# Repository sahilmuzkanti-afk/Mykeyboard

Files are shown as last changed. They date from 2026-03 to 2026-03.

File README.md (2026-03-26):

This is my personal 81% mechanical keyboard 
using a Raspberry Pi Pico (RP2040) microcontroller, custom PCB, matrix wiring with diodes, USBC connectivity, and programmable firmware.

To use this , 
i will assemble all the parts and flash the included firmware onto the microcontroller. Once assembled and programmed, the keyboard functions as a fully customizable mechanical keyboard.

I built this keyboard to learn more about PCB design and hardware projects. 
It was also a fun way to create something useful for everyday typing and coding.

FREE CAD SOURCE FILE ( DUE TO 25 MB LIMIT )
https://drive.google.com/file/d/17SE7lhAPqHGHGGqQkhNdOv5Vobzph8jl/view?usp=sharing
PCB
BOTTOM
ASSEMBLY
ASSEMBLY 2nd angle
TOP
SCHEMATIC
PLATE
PCB STEP
PCB 3D VIEW
ERC ( 0 ERROR )
DRC ( 0 ERROR )



## Bill of Materials (BOM)

| Component | Quantity | Description | Price (USD) | Supplier | Link |
|---|---|---|---|---|---|
| Raspberry Pi Pico | 1 | RP2040 microcontroller board used to control the keyboard | $8.34 | Amazon | https://amzn.in/d/0fqm6Hu0 |
| Gateron KS-9 Key Switches | 81 | Mechanical keyboard switches for each key | $25.37 | Amazon | https://amzn.in/d/0cwz2P6f |
| 1N4148 Diode | 81 | Signal diode used in keyboard matrix to prevent ghosting | $2.74 | Amazon | https://amzn.in/d/0dybXXSo4 |
| M3x16mm Screws | 50 | Screws used to mount keyboard case and PCB | $2.23 | Amazon | https://amzn.in/d/06ymnZXY |
| Mechanical Keyboard Keycap Set | 81 | Keycaps used for mechanical keyboard switches | $15.69 | Amazon | https://amzn.in/d/022G7hkw |
| Cherry Clip-in Stabilizers | 1 | Stabilizer kit for large keys | $8.98 | Keebsmod | https://www.keebsmod.com/products/cherry-clip-in-stabilizers |
| Custom Keyboard PCB | 1 | Custom PCB manufactured for the keyboard | $33.85 | JLCPCB | Cart screenshot in README |
| **Total Project Cost** |  |  | **$97.20** |  |  |

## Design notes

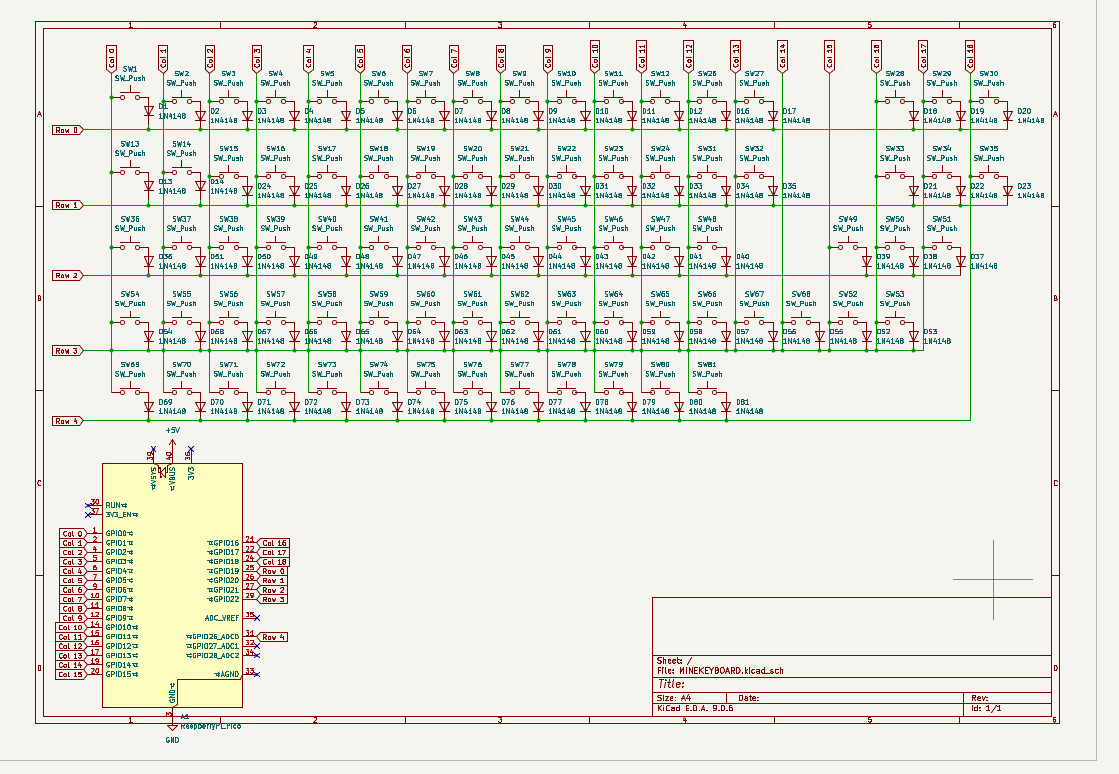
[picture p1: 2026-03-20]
IMAGES/SCHEMATIC.png

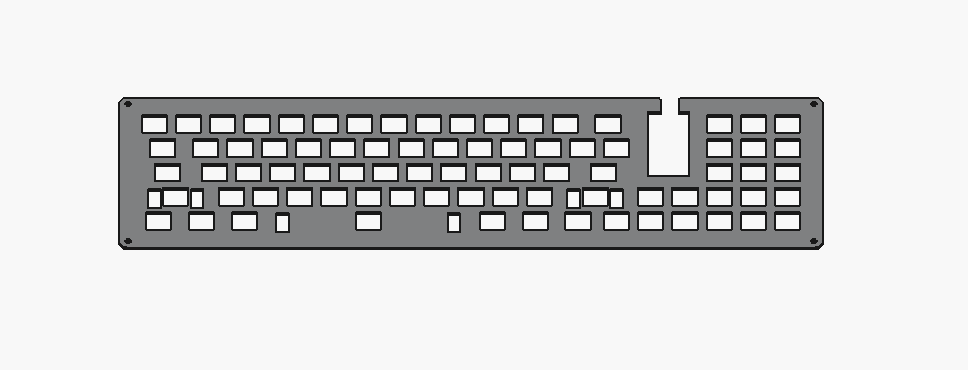
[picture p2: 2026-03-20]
IMAGES/PLATE.png

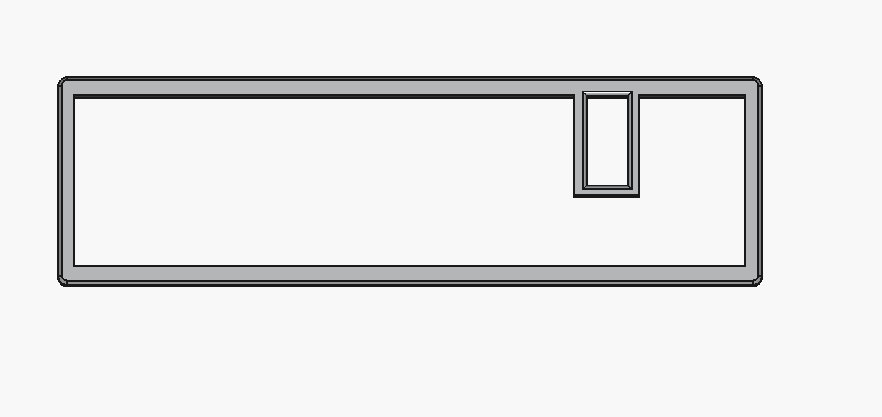
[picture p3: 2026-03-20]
IMAGES/TOP.png

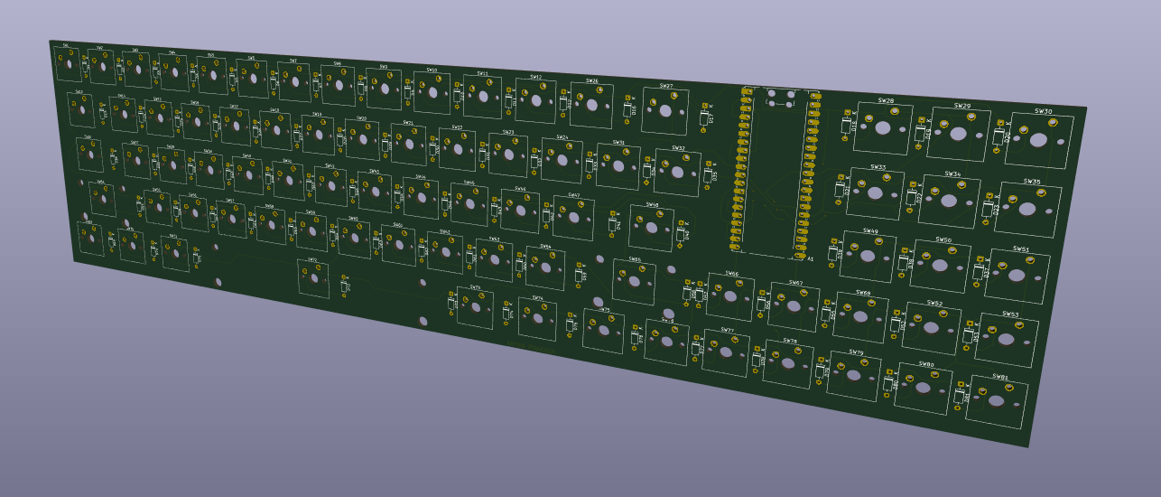
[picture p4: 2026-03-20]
IMAGES/PCB 3D VIEW.png

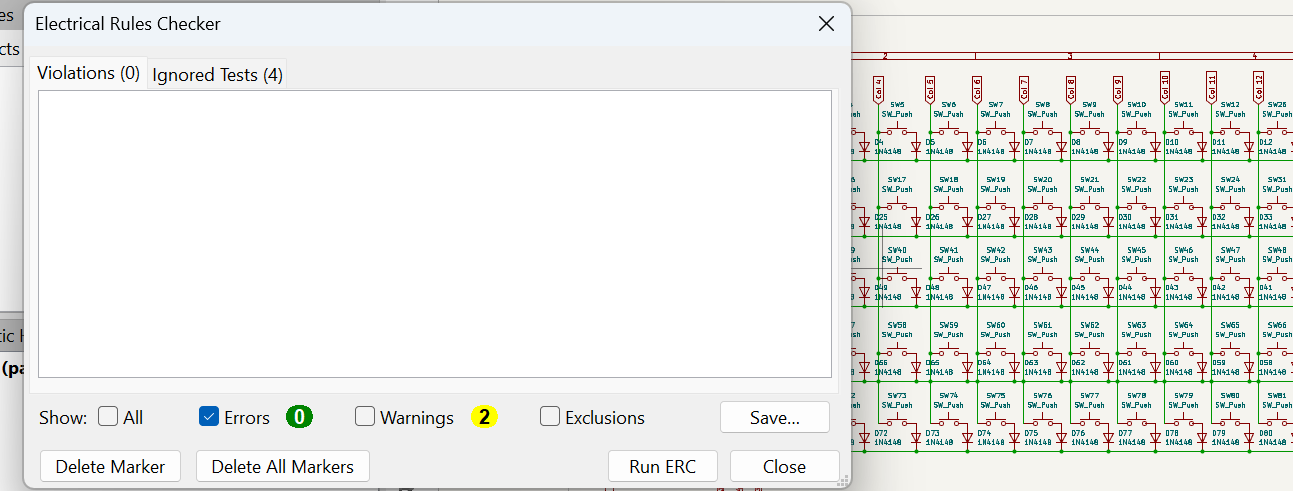
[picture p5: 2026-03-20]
IMAGES/ERC ( 0 ERROR ).png

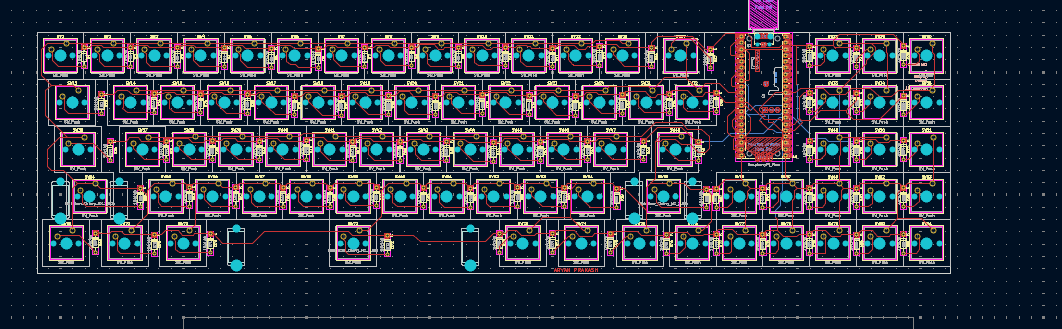
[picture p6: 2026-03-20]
IMAGES/PCB.png

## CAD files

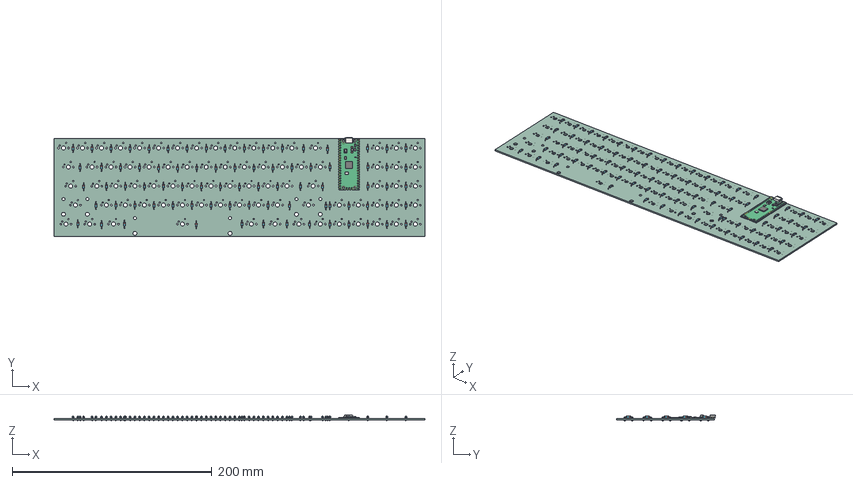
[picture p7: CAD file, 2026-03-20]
CAD/MYPCB.step
371.7 x 99.0 x 6.20 mm
D_DO-35_SOD27_P7.62mm_Horizontal x 80
RaspberryPi_Pico_Module_KiCad
CodeBoard_PCB

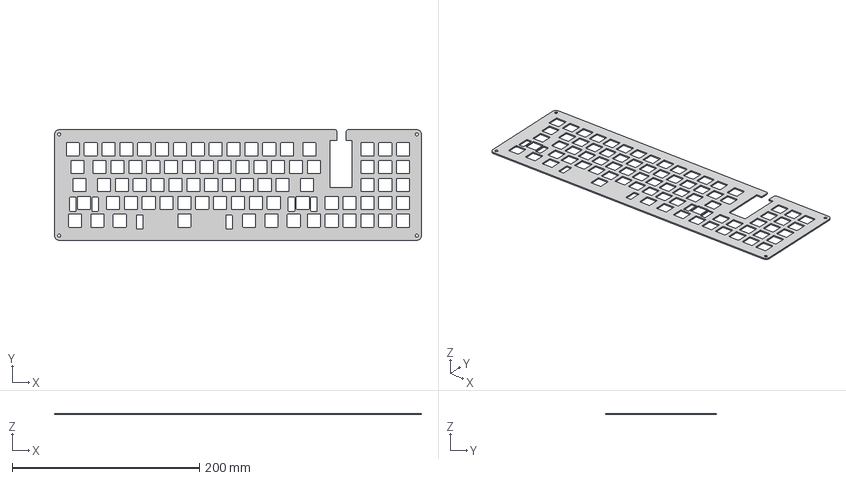
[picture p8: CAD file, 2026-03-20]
CAD/PLATE.step
391.6 x 118.0 x 1.50 mm

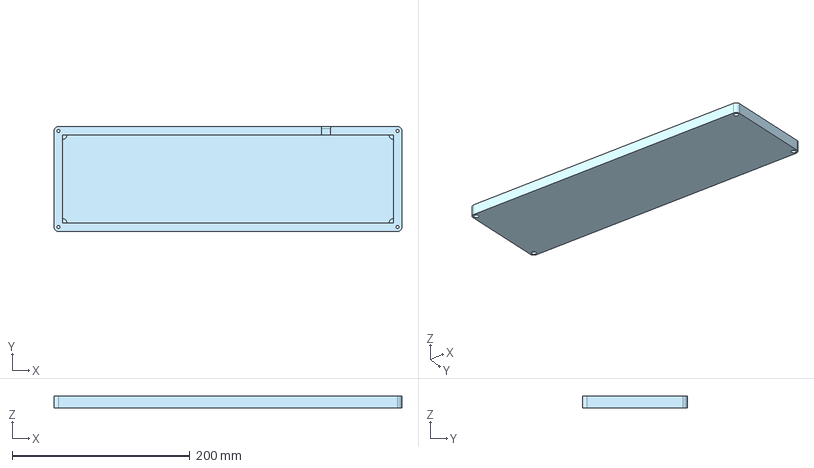
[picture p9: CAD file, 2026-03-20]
CAD/BOTTOM.step
391.6 x 118.0 x 13.0 mm

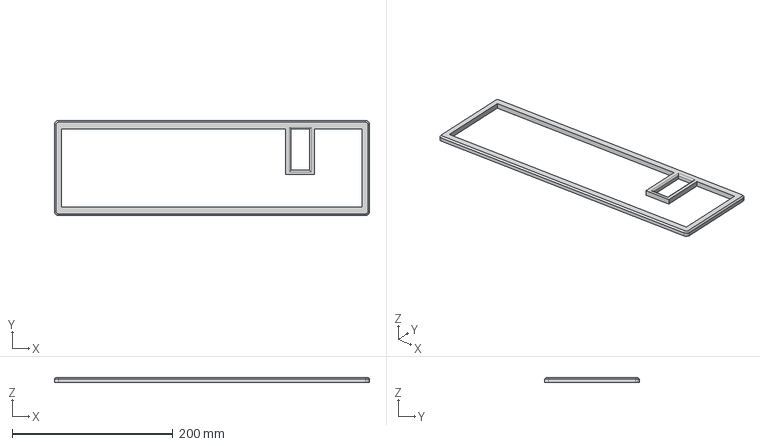
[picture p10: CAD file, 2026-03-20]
CAD/TOP.step
391.6 x 118.0 x 6.50 mm

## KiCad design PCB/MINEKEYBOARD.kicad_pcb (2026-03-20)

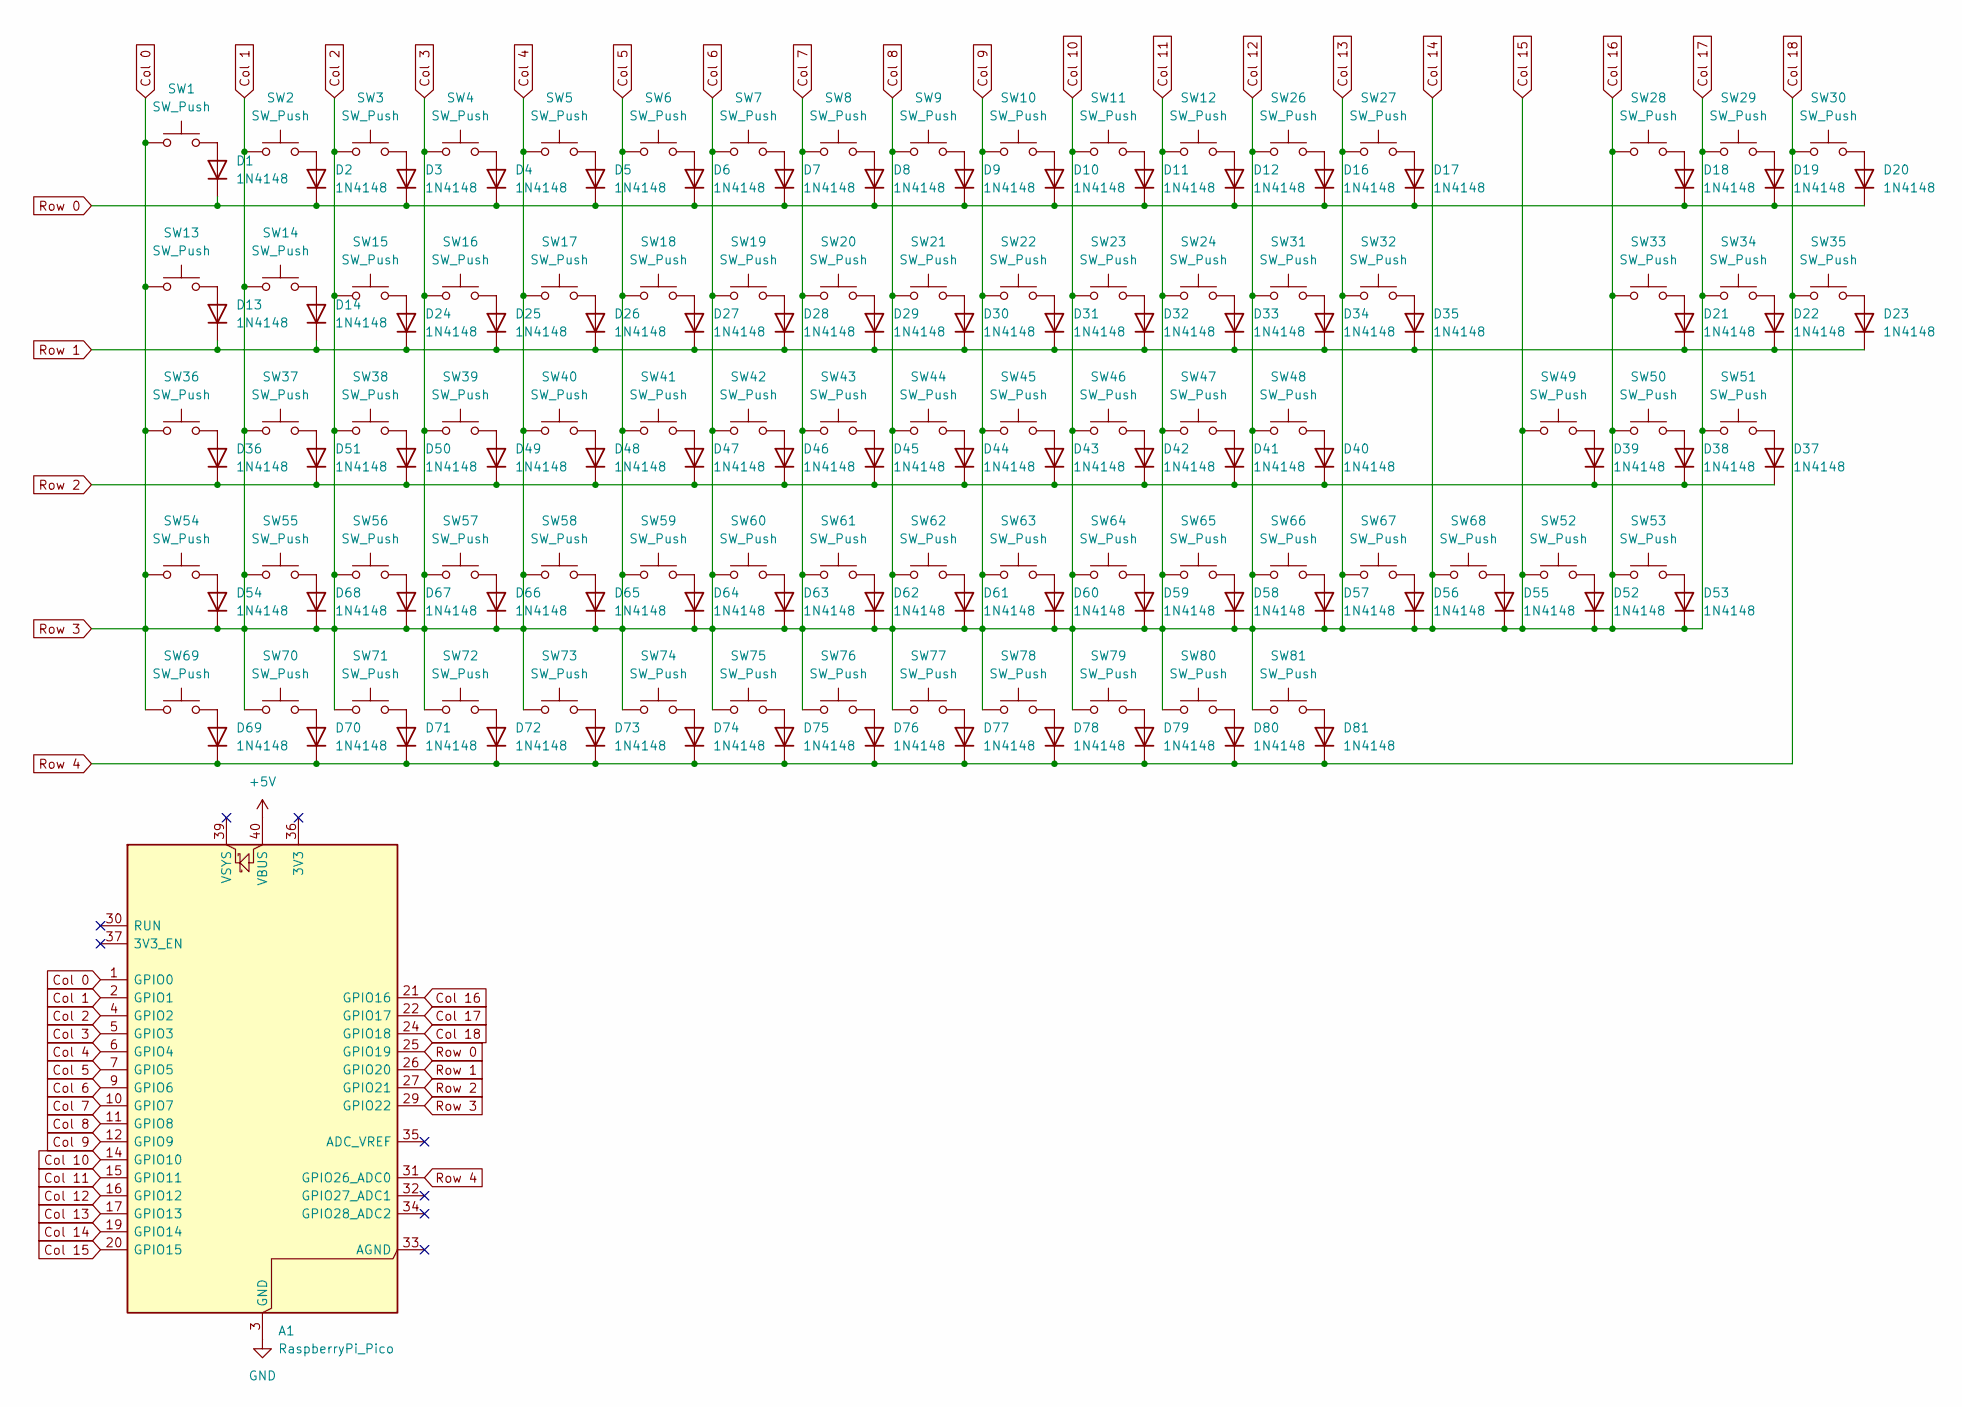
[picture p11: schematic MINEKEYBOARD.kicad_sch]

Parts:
A1: RaspberryPi_Pico; RaspberryPi_Pico_Common_Unspecified
D1, D2, D3, D4, D5, D6, D7, D8, D9, D10, D11, D12, D13, D14, D16, D17, D18, D19, D20, D21, D22, D23, D24, D25, D26, D27, D28, D29, D30, D31, D32, D33, D34, D35, D36, D37, D38, D39, D40, D41, D42, D43, D44, D45, D46, D47, D48, D49, D50, D51, D52, D53, D54, D55, D56, D57, D58, D59, D60, D61, D62, D63, D64, D65, D66, D67, D68, D69, D70, D71, D72, D73, D74, D75, D76, D77, D78, D79, D80, D81: 1N4148; D_DO-35_SOD27_P7.62mm_Horizontal
SW1, SW2, SW3, SW4, SW5, SW6, SW7, SW8, SW9, SW10, SW11, SW12, SW13, SW14, SW15, SW16, SW17, SW18, SW19, SW20, SW21, SW22, SW23, SW24, SW26, SW27, SW28, SW29, SW30, SW31, SW32, SW33, SW34, SW35, SW36, SW37, SW38, SW39, SW40, SW41, SW42, SW43, SW44, SW45, SW46, SW47, SW48, SW49, SW50, SW51, SW52, SW53, SW54, SW55, SW56, SW57, SW58, SW59, SW60, SW61, SW62, SW63, SW64, SW65, SW66, SW67, SW68, SW69, SW70, SW71, SW72, SW73, SW74, SW75, SW76, SW77, SW78, SW79, SW80, SW81: SW_Push; SW_Cherry_MX_1.00u_PCB

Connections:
+5V: A1.40 (VBUS)
Col 0: A1.1 (GPIO0), A1.2 (GPIO1), A1.4 (GPIO2), A1.5 (GPIO3), A1.6 (GPIO4), A1.7 (GPIO5), A1.9 (GPIO6), A1.10 (GPIO7), A1.11 (GPIO8), A1.12 (GPIO9), A1.14 (GPIO10), A1.15 (GPIO11), A1.16 (GPIO12), A1.17 (GPIO13), A1.19 (GPIO14), A1.20 (GPIO15), A1.21 (GPIO16), A1.22 (GPIO17), A1.29 (GPIO22), D52.1 (K), D53.1 (K), D54.1 (K), D55.1 (K), D56.1 (K), D57.1 (K), D58.1 (K), D59.1 (K), D60.1 (K), D61.1 (K), D62.1 (K), D63.1 (K), D64.1 (K), D65.1 (K), D66.1 (K), D67.1 (K), D68.1 (K), SW1.1, SW2.1, SW3.1, SW4.1, SW5.1, SW6.1, SW7.1, SW8.1, SW9.1, SW10.1, SW11.1, SW12.1, SW13.1, SW14.1, SW15.1, SW16.1, SW17.1, SW18.1, SW19.1, SW20.1, SW21.1, SW22.1, SW23.1, SW24.1, SW26.1, SW27.1, SW28.1, SW29.1, SW31.1, SW32.1, SW33.1, SW34.1, SW36.1, SW37.1, SW38.1, SW39.1, SW40.1, SW41.1, SW42.1, SW43.1, SW44.1, SW45.1, SW46.1, SW47.1, SW48.1, SW49.1, SW50.1, SW51.1, SW52.1, SW53.1, SW54.1, SW55.1, SW56.1, SW57.1, SW58.1, SW59.1, SW60.1, SW61.1, SW62.1, SW63.1, SW64.1, SW65.1, SW66.1, SW67.1, SW68.1, SW69.1, SW70.1, SW71.1, SW72.1, SW73.1, SW74.1, SW75.1, SW76.1, SW77.1, SW78.1, SW79.1, SW80.1, SW81.1
Col 18: A1.24 (GPIO18), A1.31 (GPIO26_ADC0), D69.1 (K), D70.1 (K), D71.1 (K), D72.1 (K), D73.1 (K), D74.1 (K), D75.1 (K), D76.1 (K), D77.1 (K), D78.1 (K), D79.1 (K), D80.1 (K), D81.1 (K), SW30.1, SW35.1
GND: A1.3 (GND), A1.8 (GND), A1.13 (GND), A1.18 (GND), A1.23 (GND), A1.28 (GND), A1.38 (GND)
unnamed: D1.2 (A), SW1.2
unnamed: D2.2 (A), SW2.2
unnamed: D3.2 (A), SW3.2
unnamed: D4.2 (A), SW4.2
unnamed: D5.2 (A), SW5.2
unnamed: D6.2 (A), SW6.2
unnamed: D7.2 (A), SW7.2
unnamed: D8.2 (A), SW8.2
unnamed: D9.2 (A), SW9.2
unnamed: D10.2 (A), SW10.2
unnamed: D11.2 (A), SW11.2
unnamed: D12.2 (A), SW12.2
unnamed: D13.2 (A), SW13.2
unnamed: D14.2 (A), SW14.2
unnamed: D16.2 (A), SW26.2
unnamed: D17.2 (A), SW27.2
unnamed: D18.2 (A), SW28.2
unnamed: D19.2 (A), SW29.2
unnamed: D20.2 (A), SW30.2
unnamed: D21.2 (A), SW33.2
unnamed: D22.2 (A), SW34.2
unnamed: D23.2 (A), SW35.2
unnamed: D24.2 (A), SW15.2
unnamed: D25.2 (A), SW16.2
unnamed: D26.2 (A), SW17.2
unnamed: D27.2 (A), SW18.2
unnamed: D28.2 (A), SW19.2
unnamed: D29.2 (A), SW20.2
unnamed: D30.2 (A), SW21.2
unnamed: D31.2 (A), SW22.2
unnamed: D32.2 (A), SW23.2
unnamed: D33.2 (A), SW24.2
unnamed: D34.2 (A), SW31.2
unnamed: D35.2 (A), SW32.2
unnamed: D36.2 (A), SW36.2
unnamed: D37.2 (A), SW51.2
unnamed: D38.2 (A), SW50.2
unnamed: D39.2 (A), SW49.2
unnamed: D40.2 (A), SW48.2
unnamed: D41.2 (A), SW47.2
unnamed: D42.2 (A), SW46.2
unnamed: D43.2 (A), SW45.2
unnamed: D44.2 (A), SW44.2
unnamed: D45.2 (A), SW43.2
unnamed: D46.2 (A), SW42.2
unnamed: D47.2 (A), SW41.2
unnamed: D48.2 (A), SW40.2
unnamed: D49.2 (A), SW39.2
unnamed: D50.2 (A), SW38.2
unnamed: D51.2 (A), SW37.2
unnamed: D52.2 (A), SW52.2
unnamed: D53.2 (A), SW53.2
unnamed: D54.2 (A), SW54.2
unnamed: D55.2 (A), SW68.2
unnamed: D56.2 (A), SW67.2
unnamed: D57.2 (A), SW66.2
unnamed: D58.2 (A), SW65.2
unnamed: D59.2 (A), SW64.2
unnamed: D60.2 (A), SW63.2
unnamed: D61.2 (A), SW62.2
unnamed: D62.2 (A), SW61.2
unnamed: D63.2 (A), SW60.2
unnamed: D64.2 (A), SW59.2
unnamed: D65.2 (A), SW58.2
unnamed: D66.2 (A), SW57.2
unnamed: D67.2 (A), SW56.2
unnamed: D68.2 (A), SW55.2
unnamed: D69.2 (A), SW69.2
unnamed: D70.2 (A), SW70.2
unnamed: D71.2 (A), SW71.2
unnamed: D72.2 (A), SW72.2
unnamed: D73.2 (A), SW73.2
unnamed: D74.2 (A), SW74.2
unnamed: D75.2 (A), SW75.2
unnamed: D76.2 (A), SW76.2
unnamed: D77.2 (A), SW77.2
unnamed: D78.2 (A), SW78.2
unnamed: D79.2 (A), SW79.2
unnamed: D80.2 (A), SW80.2
unnamed: D81.2 (A), SW81.2
Row 0: A1.25 (GPIO19), D1.1 (K), D2.1 (K), D3.1 (K), D4.1 (K), D5.1 (K), D6.1 (K), D7.1 (K), D8.1 (K), D9.1 (K), D10.1 (K), D11.1 (K), D12.1 (K), D16.1 (K), D17.1 (K), D18.1 (K), D19.1 (K), D20.1 (K)
Row 1: A1.26 (GPIO20), D13.1 (K), D14.1 (K), D21.1 (K), D22.1 (K), D23.1 (K), D24.1 (K), D25.1 (K), D26.1 (K), D27.1 (K), D28.1 (K), D29.1 (K), D30.1 (K), D31.1 (K), D32.1 (K), D33.1 (K), D34.1 (K), D35.1 (K)
Row 2: A1.27 (GPIO21), D36.1 (K), D37.1 (K), D38.1 (K), D39.1 (K), D40.1 (K), D41.1 (K), D42.1 (K), D43.1 (K), D44.1 (K), D45.1 (K), D46.1 (K), D47.1 (K), D48.1 (K), D49.1 (K), D50.1 (K), D51.1 (K)

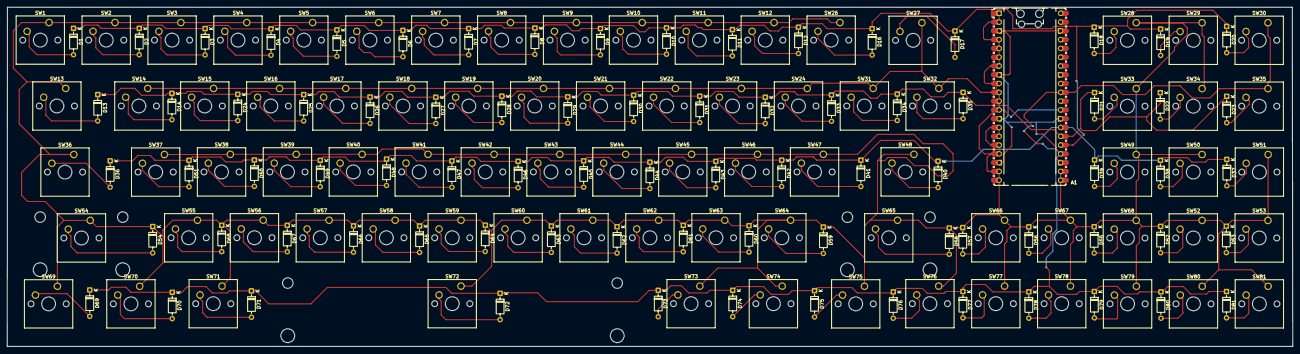
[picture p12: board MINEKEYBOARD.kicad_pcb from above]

Board: 2 copper layers, 371.7 x 98.1 mm, 161 parts (0 on the bottom side), 86 nets.

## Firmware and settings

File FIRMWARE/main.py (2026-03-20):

import board

from kmk.kmk_keyboard import KMKKeyboard
from kmk.keys import KC
from kmk.scanners import DiodeOrientation
from kmk.modules.macros import Press, Release, Tap, Macros

keyboard = KMKKeyboard()

macros = Macros()
keyboard.modules.append(macros)

keyboard.col_pins = (board.GP0, board.GP1, board.GP2, board.GP3, board.GP4, board.GP5, board.GP6, board.GP7, board.GP8, board.GP9, board.GP10, board.GP11, board.GP12, board.GP13, board.GP14, board.GP15, board.GP16, board.GP17, board.GP18)
keyboard.row_pins = (board.GP18, board.GP19, board.GP20, board.GP21, board.GP22)
keyboard.diode_orientation = DiodeOrientation.COL2ROW

keyboard.keymap = [
    [KC.ESC, KC.N1, KC.N2, KC.N3, KC.N4, KC.N5, KC.N6, KC.N7, KC.N8, KC.N9, KC.N0, KC.MINUS, KC.EQUAL, KC.BSPACE, KC.NO, KC.NO, KC.EQUAL, KC.MACRO([Press(KC.LPRN), Press(KC.RPRN), Tap(KC.LEFT)]), KC.MACRO([Press(KC.LCBR), Press(KC.RCBR), Tap(KC.LEFT)])],
    [KC.TAB, KC.Q, KC.W, KC.E, KC.R, KC.T, KC.Y, KC.U, KC.I, KC.O, KC.P, KC.LBRACKET, KC.RBRACKET, KC.BSLASH, KC.NO, KC.NO, KC.PLUS, KC.MACRO([Tap(KC.LBRACKET), Tap(KC.RBRACKET), Tap(KC.LEFT)]), KC.MACRO([Tap(KC.QUOTE), Tap(KC.QUOTE), Tap(KC.LEFT)])],
    [KC.CAPSLOCK, KC.A, KC.S, KC.D, KC.F, KC.G, KC.H, KC.J, KC.K, KC.L, KC.SCOLON, KC.QUOTE, KC.ENTER, KC.NO, KC.NO, KC.MINUS, KC.COLON],
    [KC.LSHIFT, KC.Z, KC.X, KC.C, KC.V, KC.B, KC.N, KC.M, KC.COMMA, KC.DOT, KC.SLASH, KC.UP, KC.DOWN, KC.SLASH, KC.LABK, KC.RABK],
    [KC.LCTRL, KC.LALT, KC.LCMD, KC.SPACE, KC.RCMD, KC.RALT, KC.RCTRL, KC.GRAVE, KC.LEFT, KC.RIGHT, KC.ASTERISK, KC.BSLASH, KC.EXCLAIM]
]

if __name__ == '__main__':
    keyboard.go()
